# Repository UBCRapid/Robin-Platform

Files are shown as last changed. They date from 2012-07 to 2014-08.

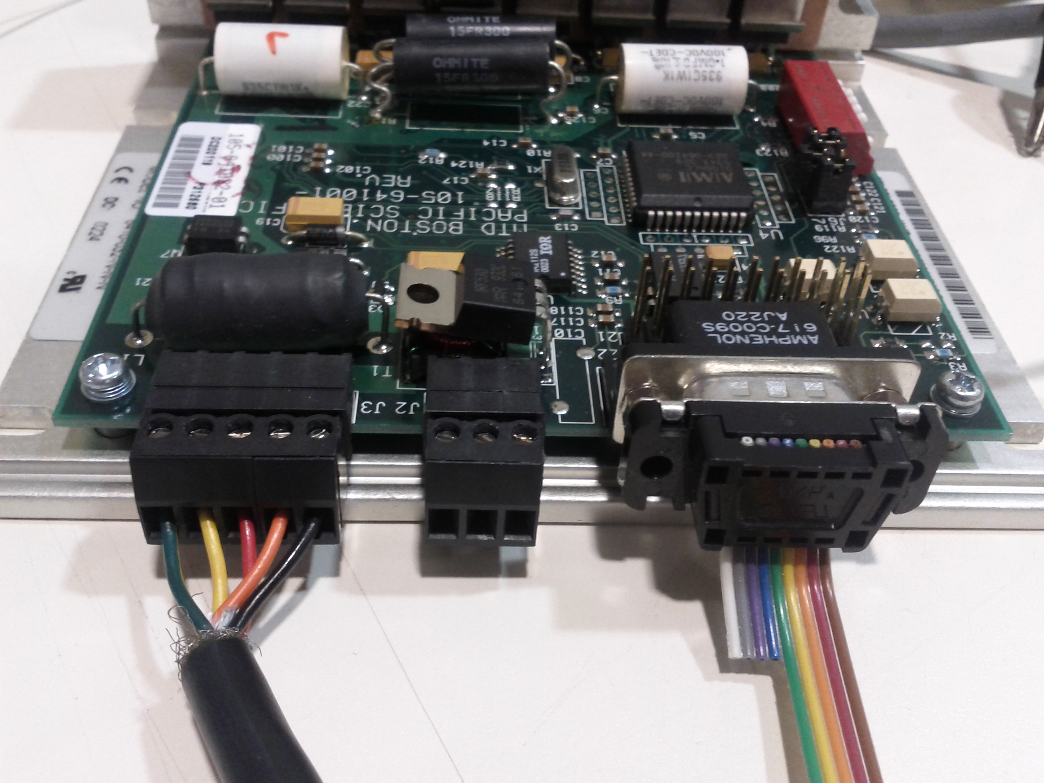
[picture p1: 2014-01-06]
Documentation/Stepper Driver Wiring Pic.jpg

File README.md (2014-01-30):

UBC Rapid
=========

Robin
---------

An [Automated Liquid Handling machine](http://en.wikipedia.org/wiki/Liquid_handling_robot) from the biomed industry, Robin is being modified into some form of 3D printer.  Robin is sometimes refered to as "that big blue thing in the corner".

Robin has industrial-grade stepper drivers and linear stages. In comparison to our 3d printers we regularly build the machine's precision and ease of use blows them out of the water. The documentation is very extensive but very helpful. The important things that are consulted often have been screenshotted.

This project is currently being led and mostly worked on by Scott Pidzarko. Feel free to get involved or ask him questions. 

The machine currently can move it's x,y, and z axis from Prontrface or any other software that works with the Marlin firmware. Endstops are in the process of being wired: if you understand well how opto-endstops work please feel free to explain them to Scott - he would love to save time and avoid headaches.

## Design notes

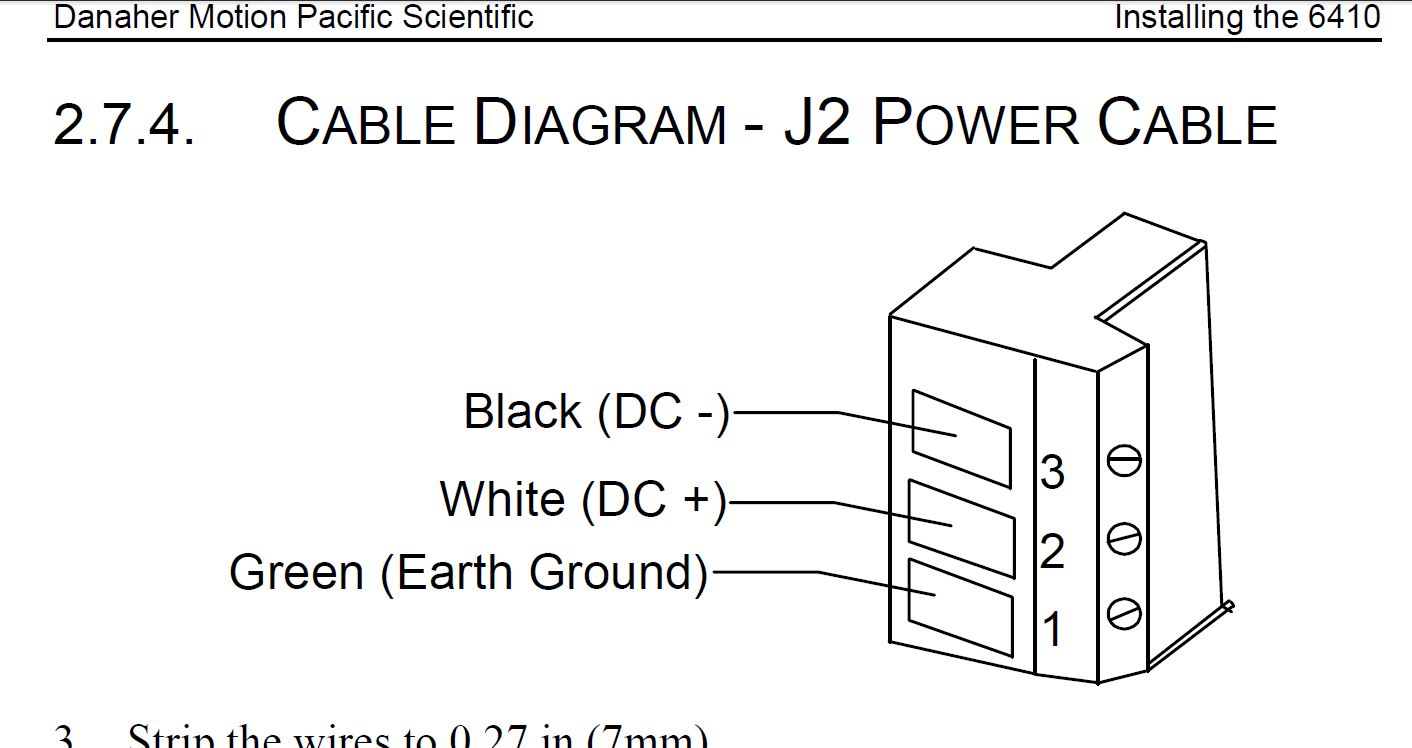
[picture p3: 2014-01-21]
Documentation/Power (J2) pinout.PNG

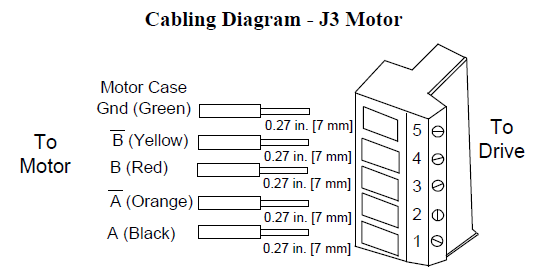
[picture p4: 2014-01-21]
Documentation/Motor (J3) Pinout.PNG

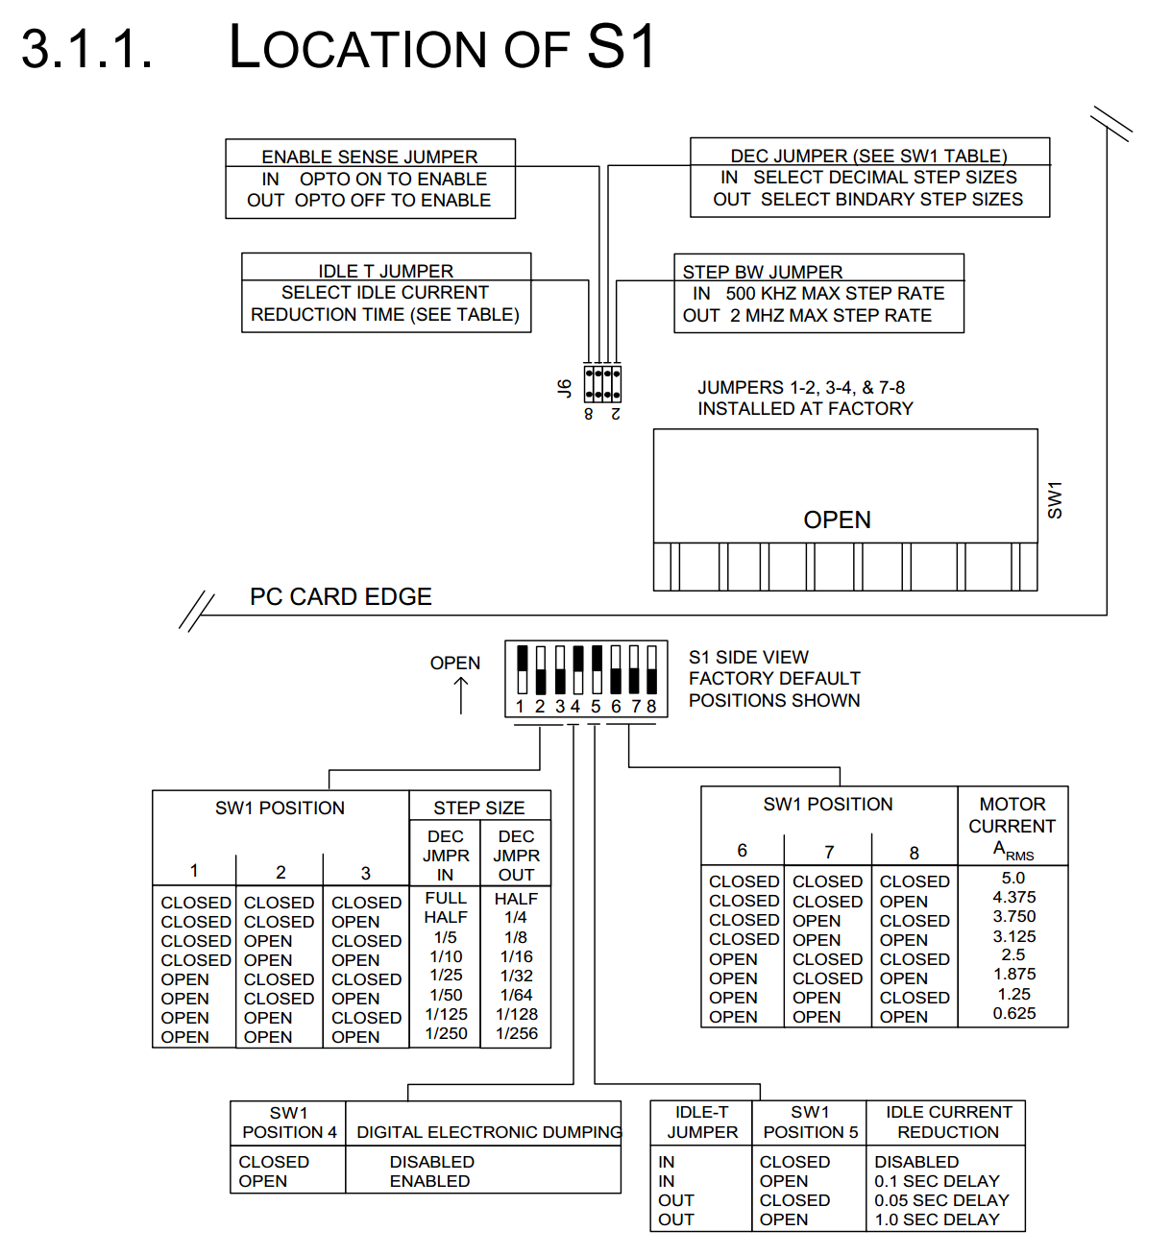
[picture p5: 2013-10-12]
Documentation/Pacific Scientific dipswitch pinout.png

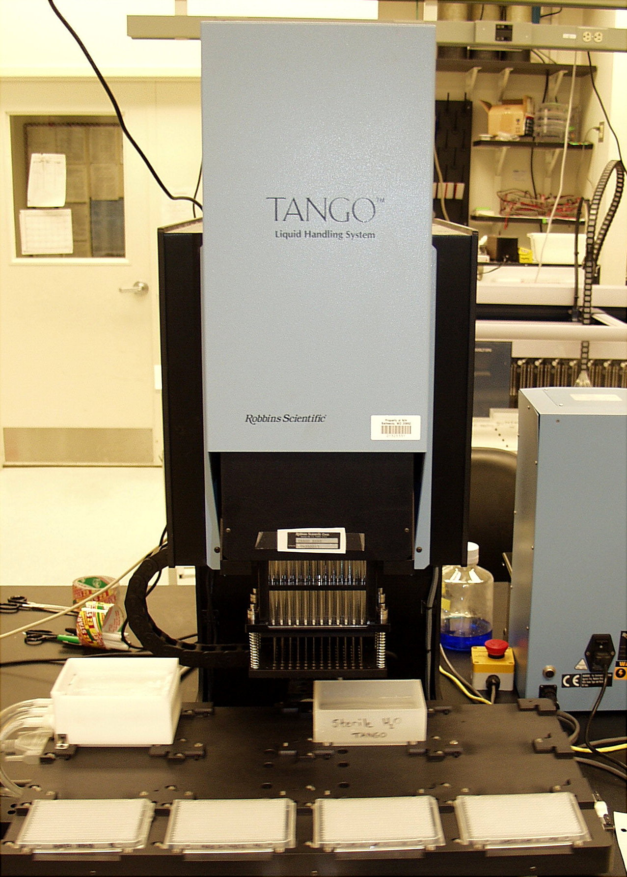
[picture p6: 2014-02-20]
NHGRI-27963.jpg

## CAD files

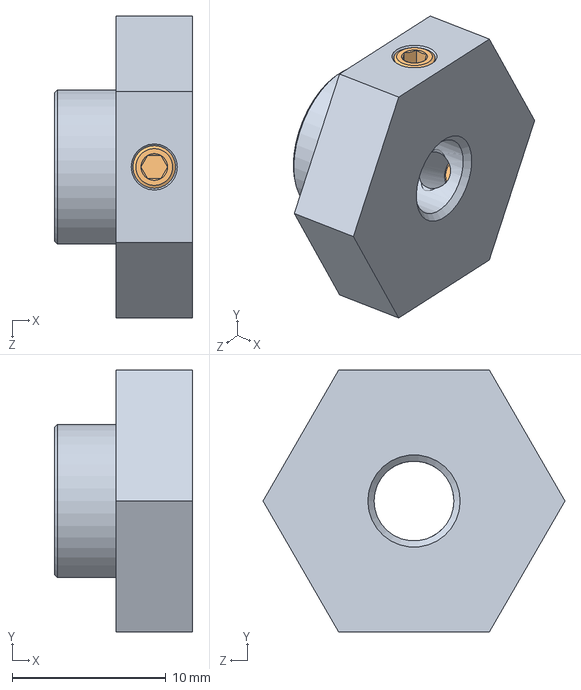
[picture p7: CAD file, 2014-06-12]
Solidworks/BNSCS6.sldasm
9.00 x 17.0 x 19.6 mm
BNSCS6_part
Hexagon_socket_set_screw_with_flat_point_DIN_913___M3x3 x 2

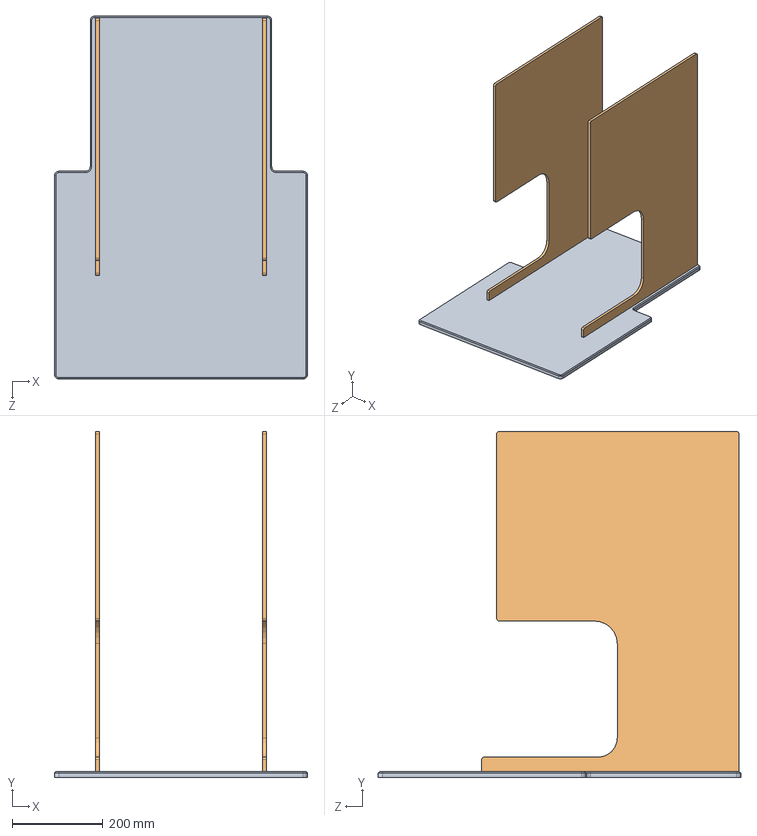
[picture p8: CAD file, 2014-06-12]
Solidworks/Robin_platform.SLDASM
558.0 x 763.0 x 800.0 mm
Base
side_piece x 2

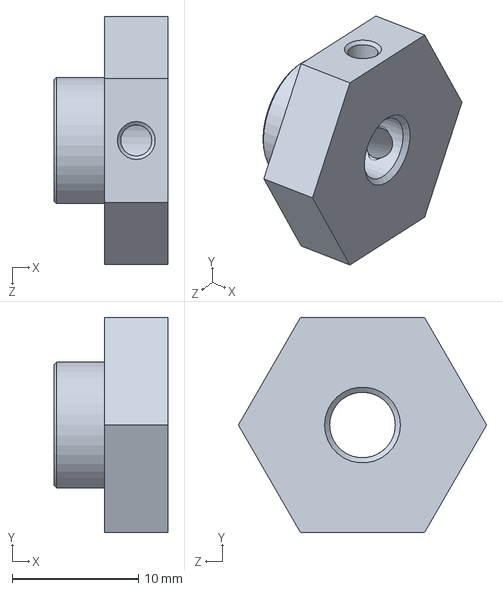
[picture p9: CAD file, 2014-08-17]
Solidworks/BNSCS6_part.sldprt
9.00 x 17.0 x 19.6 mm

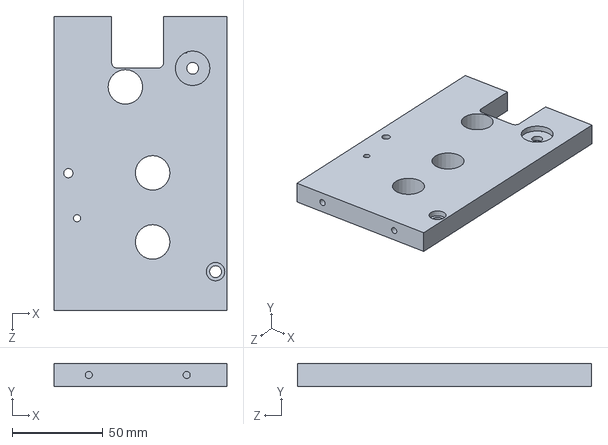
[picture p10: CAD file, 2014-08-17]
Solidworks/A0002.SLDPRT
95.2 x 12.8 x 161.9 mm

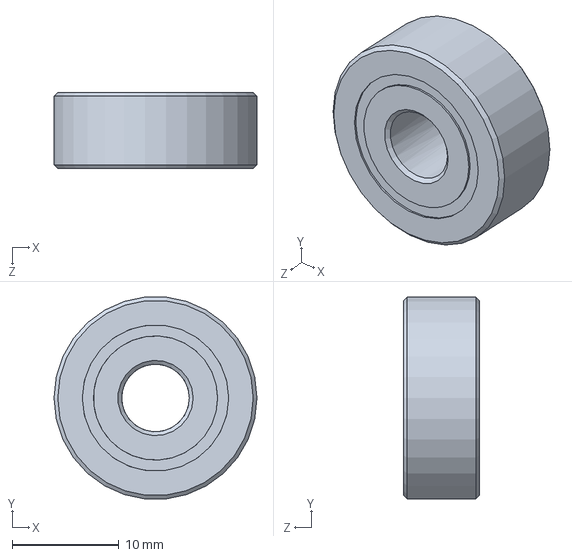
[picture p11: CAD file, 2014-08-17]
Solidworks/1-4x3-4x9-32_2342K184.SLDPRT
19.1 x 18.9 x 7.14 mm

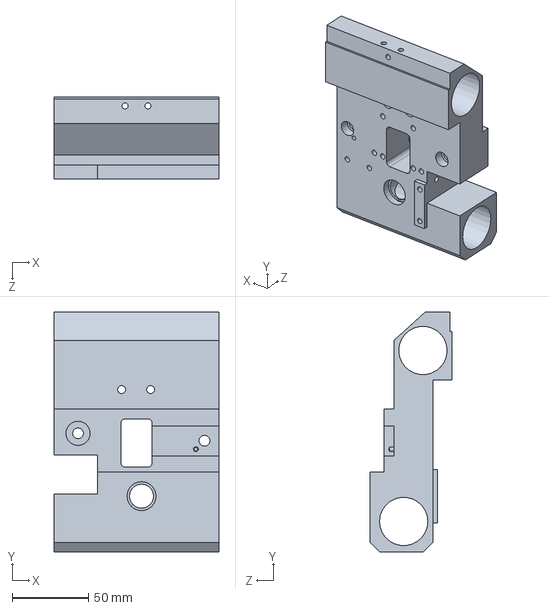
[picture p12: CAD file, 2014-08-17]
Solidworks/B0001.SLDPRT
108.0 x 157.2 x 54.0 mm

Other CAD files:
Documentation/260cat1.dwg
Documentation/404XR-DXF/404xr250.dxf
Documentation/404XR-DXF/404xr050.dxf
Solidworks/A0006.sldprt
Documentation/404XR-DXF/404xr600.dxf
Documentation/404XR-DXF/404xr400.dxf
Solidworks/A0007.sldprt
Documentation/404XR-DXF/404xr500.dxf
Documentation/404XR-DXF/404xr550.dxf
Documentation/404XR-DXF/404xr450.dxf
Documentation/404XR-DXF/404xr300.dxf
Documentation/404XR-DXF/404xr100.dxf
Documentation/404XR-DXF/404xr150.dxf
Documentation/404XR-DXF/404xr200.dxf
Documentation/404XR-DXF/404xr350.dxf
Solidworks/3-4in_ss_6262K850.SLDPRT
Solidworks/A0001.SLDPRT
Solidworks/A0003.sldprt
Solidworks/Base.SLDPRT
Solidworks/CNC_plate.SLDPRT
Solidworks/EVA_nut_flats.SLDPRT
Solidworks/Front plate.SLDPRT
Solidworks/Leadscrew_Z-axis^Bernhard_01.sldprt
Solidworks/bracket.SLDPRT
Solidworks/side_piece.SLDPRT
Solidworks/vert_support_plate.SLDPRT

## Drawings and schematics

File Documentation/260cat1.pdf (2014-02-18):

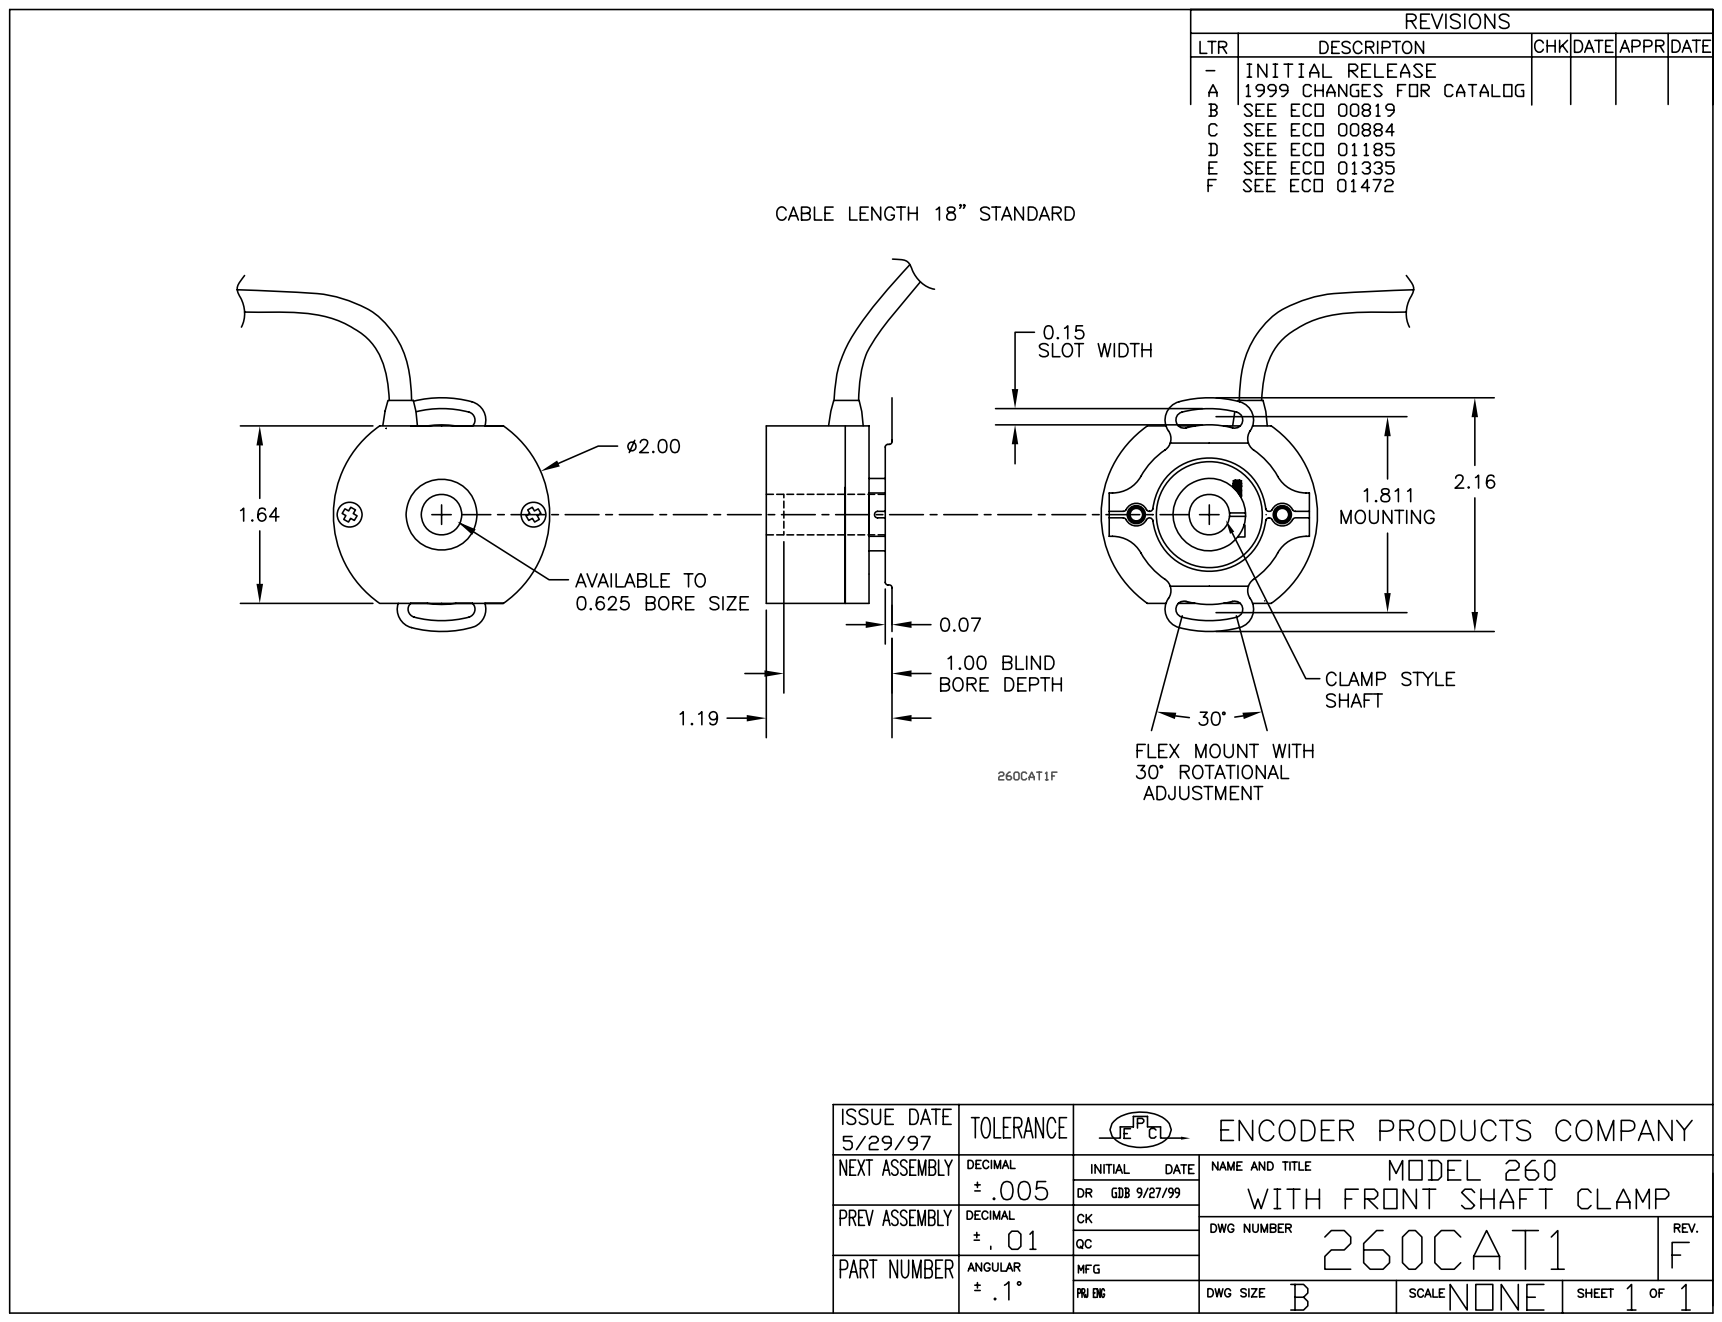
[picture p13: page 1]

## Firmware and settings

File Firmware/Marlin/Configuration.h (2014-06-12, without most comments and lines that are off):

#define CONFIGURATION_H
#define STRING_VERSION_CONFIG_H __DATE__ " " __TIME__ // build date and time
#define STRING_CONFIG_H_AUTHOR "(Scott Pidzarko)" // Who made the changes.
#define SERIAL_PORT 0
#define BAUDRATE 250000
#define MOTHERBOARD 33
#define EXTRUDERS 1
#define POWER_SUPPLY 1
#define TEMP_SENSOR_0 -1
#define TEMP_SENSOR_1 -1
#define TEMP_SENSOR_2 0
#define TEMP_SENSOR_BED 0
#define MAX_REDUNDANT_TEMP_SENSOR_DIFF 10
#define TEMP_RESIDENCY_TIME 10  // (seconds)
#define TEMP_HYSTERESIS 3       // (degC) range of +/- temperatures considered "close" to the target one
#define TEMP_WINDOW     1       // (degC) Window around target to start the residency timer x degC early.
#define HEATER_0_MINTEMP 5
#define HEATER_1_MINTEMP 5
#define HEATER_2_MINTEMP 5
#define BED_MINTEMP 5
#define HEATER_0_MAXTEMP 275
#define HEATER_1_MAXTEMP 275
#define HEATER_2_MAXTEMP 275
#define BED_MAXTEMP 150
#define PIDTEMP
#define BANG_MAX 255 // limits current to nozzle while in bang-bang mode; 255=full current
#define PID_MAX 255 // limits current to nozzle while PID is active (see PID_FUNCTIONAL_RANGE below); 255=full current
  #define PID_FUNCTIONAL_RANGE 10 // If the temperature difference between the target temperature and the actual temperature
  #define PID_INTEGRAL_DRIVE_MAX 255  //limit for the integral term
  #define K1 0.95 //smoothing factor within the PID
  #define PID_dT ((16.0 * 8.0)/(F_CPU / 64.0 / 256.0)) //sampling period of the temperature routine
    #define  DEFAULT_Kp 22.2
    #define  DEFAULT_Ki 1.08
    #define  DEFAULT_Kd 114
#define MAX_BED_POWER 255 // limits duty cycle to bed; 255=full current
#define PREVENT_DANGEROUS_EXTRUDE
#define PREVENT_LENGTHY_EXTRUDE
#define EXTRUDE_MINTEMP 170
#define EXTRUDE_MAXLENGTH (X_MAX_LENGTH+Y_MAX_LENGTH) //prevent extrusion of very large distances.
#define ENDSTOPPULLUPS // Comment this out (using // at the start of the line) to disable the endstop pullup resistors
  #define ENDSTOPPULLUP_XMAX
  #define ENDSTOPPULLUP_YMAX
  #define ENDSTOPPULLUP_ZMAX
  #define ENDSTOPPULLUP_XMIN
  #define ENDSTOPPULLUP_YMIN
  #define ENDSTOPPULLUP_ZMIN
const bool X_MIN_ENDSTOP_INVERTING = false; // set to true to invert the logic of the endstop.
const bool Y_MIN_ENDSTOP_INVERTING = false; // set to true to invert the logic of the endstop.
const bool Z_MIN_ENDSTOP_INVERTING = true; // set to true to invert the logic of the endstop.
const bool X_MAX_ENDSTOP_INVERTING = false; // set to true to invert the logic of the endstop.
const bool Y_MAX_ENDSTOP_INVERTING = false; // set to true to invert the logic of the endstop.
const bool Z_MAX_ENDSTOP_INVERTING = true; // set to true to invert the logic of the endstop.
#if defined(COREXY) && !defined(DISABLE_MAX_ENDSTOPS)
  #define DISABLE_MAX_ENDSTOPS
#endif
#define X_ENABLE_ON 0
#define Y_ENABLE_ON 0
#define Z_ENABLE_ON 0
#define E_ENABLE_ON 0 // For all extruders
#define DISABLE_X false
#define DISABLE_Y false
#define DISABLE_Z true
#define DISABLE_E true // For all extruders
#define INVERT_X_DIR false   // for Mendel set to false, for Orca set to true
#define INVERT_Y_DIR true    // for Mendel set to true, for Orca set to false
#define INVERT_Z_DIR true     // for Mendel set to false, for Orca set to true
#define INVERT_E0_DIR false   // for direct drive extruder v9 set to true, for geared extruder set to false
#define INVERT_E1_DIR false    // for direct drive extruder v9 set to true, for geared extruder set to false
#define INVERT_E2_DIR false   // for direct drive extruder v9 set to true, for geared extruder set to false
#define X_HOME_DIR -1
#define Y_HOME_DIR -1
#define Z_HOME_DIR -1
#define min_software_endstops true // If true, axis won't move to coordinates less than HOME_POS.
#define max_software_endstops true  // If true, axis won't move to coordinates greater than the defined lengths below.
#define X_MAX_POS 380
#define X_MIN_POS 0
#define Y_MAX_POS 400
#define Y_MIN_POS 0
#define Z_MAX_POS 200
#define Z_MIN_POS 0
#define X_MAX_LENGTH (X_MAX_POS - X_MIN_POS)
#define Y_MAX_LENGTH (Y_MAX_POS - Y_MIN_POS)
#define Z_MAX_LENGTH (Z_MAX_POS - Z_MIN_POS)
#define MANUAL_X_HOME_POS 0
#define MANUAL_Y_HOME_POS 0
#define MANUAL_Z_HOME_POS 0
#define NUM_AXIS 4 // The axis order in all axis related arrays is X, Y, Z, E
#define HOMING_FEEDRATE {50*60, 50*60, 4*60, 0}  // set the homing speeds (mm/min)
#define DEFAULT_AXIS_STEPS_PER_UNIT   {200.0,200.0,200.0*8/3,760*1.1}  // default steps per unit for Ultimaker --> {x,y,z,e}
#define DEFAULT_MAX_FEEDRATE          {500, 500, 5, 25}    // (mm/sec)
#define DEFAULT_MAX_ACCELERATION      {100,100,100,10000}    // X, Y, Z, E maximum start speed for accelerated moves. E default values are good for skeinforge 40+, for older versions raise them a lot.
#define DEFAULT_ACCELERATION          50    // X, Y, Z and E max acceleration in mm/s^2 for printing moves
#define DEFAULT_RETRACT_ACCELERATION  3000   // X, Y, Z and E max acceleration in mm/s^2 for retracts
#define DEFAULT_XYJERK                20.0    // (mm/sec)
#define DEFAULT_ZJERK                 0.4     // (mm/sec)
#define DEFAULT_EJERK                 5.0    // (mm/sec)
#define PLA_PREHEAT_HOTEND_TEMP 180
#define PLA_PREHEAT_HPB_TEMP 70
#define PLA_PREHEAT_FAN_SPEED 255   // Insert Value between 0 and 255
#define ABS_PREHEAT_HOTEND_TEMP 240
#define ABS_PREHEAT_HPB_TEMP 100
#define ABS_PREHEAT_FAN_SPEED 255   // Insert Value between 0 and 255
#define SOFT_PWM_SCALE 0
#include "Configuration_adv.h"
#include "thermistortables.h"

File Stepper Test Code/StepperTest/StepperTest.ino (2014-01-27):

// ****************************************************************************************************************
// NOTE: Make sure that pin 3 of the stepper driver is tied to 5V. Tying to ground will disable the stepper driver.
// ****************************************************************************************************************

#define DIR_PIN 2   // Plug into pin 2 of the stepper driver
#define STEP_PIN 3  // Plug into pin 1 of the stepper driver
#define FORWARD 1
#define BACKWARD -1
#define STEPSPERREV 200 //standard for 1.8 deg stepper motors
#define MICROSTEPSPERSTEP 10 //settable according to dipswitches on stepper driver. Decimal Stepper size increments currently set on jumpers.
//10 mm linear travel per revolution of stepper


//Set initial step size and direction
  int direction = FORWARD;
  int stepSize = STEPSPERREV * MICROSTEPSPERSTEP; //initialize stepper to turn once, so travelling 10 mm
  
void setup() 
{
  //Setup pinsM
  Serial.begin(9600);
  pinMode(DIR_PIN, OUTPUT); 
  pinMode(STEP_PIN, OUTPUT); 
}

void loop() 
{
  if (Serial.available() > 0) 
  {
    char value = Serial.read();

    if (value == 'f') // Change to forward dir
    {
      direction = FORWARD;
      Serial.println("Direction set to FORWARD");
    }
    else if (value == 'b') // Change to backward dir
    {
      Serial.println("Direction set to BACKWARD");
      direction = BACKWARD;
    }
    else if (value == 'p') // print current direction and stepsize
    {
      Serial.print("The current direction is ");
      if( direction == FORWARD )
        Serial.println("FORWARD");
      else 
        Serial.println("BACKWARD");
      Serial.print("The current step size is ");
      Serial.println(stepSize);
    } 
    else if (value == 'g') // Send movement command
    {
      Serial.println("Sending movement command");
      rotate( stepSize * direction, 1);
    }
    else if (value == '+')
    {
      stepSize *= 2;
      Serial.print("Step Size doubled. Step size now ");
      Serial.println(stepSize);
    }
    else if (value = '-')
    {
      stepSize /= 2;
      if (stepSize < 1) 
        stepSize = 1;
      Serial.print("Step size halved. Step size now ");
      Serial.println(stepSize); 
    }

  }
  delay(200);
}

void rotate(int steps, float speed){ 
  //rotate a specific number of microsteps (8 microsteps per step) - (negative for reverse movement)
  //speed is any number from .01 -> 1 with 1 being fastest - Slower is stronger
  int dir = (steps > 0)? HIGH:LOW;
  steps = abs(steps);

  digitalWrite(DIR_PIN,dir); 

  float usDelay = (1/speed) * 70;

  for(int i=0; i < steps; i++){ 
    digitalWrite(STEP_PIN, HIGH); 
    delayMicroseconds(usDelay); 

    digitalWrite(STEP_PIN, LOW); 
    delayMicroseconds(usDelay); 
  } 
} 

void rotateDeg(float deg, float speed){ 
  //rotate a specific number of degrees (negative for reverse movement)
  //speed is any number from .01 -> 1 with 1 being fastest - Slower is stronger
  int dir = (deg > 0)? HIGH:LOW;
  digitalWrite(DIR_PIN,dir); 

  int steps = abs(deg)*(1/0.225);
  float usDelay = (1/speed) * 70;

  for(int i=0; i < steps; i++){ 
    digitalWrite(STEP_PIN, HIGH); 
    delayMicroseconds(usDelay); 

    digitalWrite(STEP_PIN, LOW); 
    delayMicroseconds(usDelay); 
  } 
}

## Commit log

2013-10-12 Added documentation and stepper test code
2014-01-21 Fixed the stepper test code and updated some docs
    Made easy-to-use documentation for wiring the power, motor, and arduino
    to the stepper controller.
    Also changed issues with the stepper test code. Now confirmed to work.
    [StepperTest.ino]
2014-01-26 Added a few more better pieces of documentation
    Found an up-to-date parker linear stage manual that is exactly our
    product that Rapid has. Moved some things around in folders
2014-01-27 Changed stepper test code a bit
2014-02-18 Some pictures of original encoder/limit switch wiring
2014-02-18 added encoder docs
    [260cat1.dwg]
2014-02-23 Added latest version of the firmware
    Homes in 2D! See notebook for pinouts and current wiring. NOTE: pin 14
    on current mega is busted, look at pins.h to see alternative mapping for
    x_min endstop
    [Configuration.h, Configuration_adv.h, Menu Plans.xlsx]
2014-06-12 Added a lot of the latest stuff
    More documentation, changed pins.h and configuration.h for MEGA
    firmware, started and almost finished the solidworks work for the z axis
    and CNC mount plate
    [1-4x3-4x9-32_2342K184.SLDPRT, 3-4in_ss_6262K850.SLDPRT, 404xr050.dxf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]
2014-06-12 cnc_plate model started
    [CNC_plate.SLDPRT]
2014-06-20 Finalized z axis assembly
    [3-4in_ss_6262K850.SLDPRT, CNC_plate.SLDPRT, Z_axis_assembly.SLDASM]
2014-08-17 Updated Z axis assembly
    Updated design because machining a new plate would be challenging if not
    impossible. Used old plate and will put bracket on for spindle mount.
    [1-4x3-4x9-32_2342K184.SLDPRT, 3-4in_ss_6262K850.SLDPRT, A0001.SLDPRT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]
